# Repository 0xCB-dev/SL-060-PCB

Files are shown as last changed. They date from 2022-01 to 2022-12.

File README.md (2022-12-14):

# Synth Labs 060 PCB
## 60% Keyboard

Licence | OSHWA
:-------------------------:|:-------------------------:
 | (https://certification.oshwa.org/de000116.html)

### PCB:
KiCad version 6 Stable

#### Daughterboard
Top | Bottom
:-------------------------:|:-------------------------:
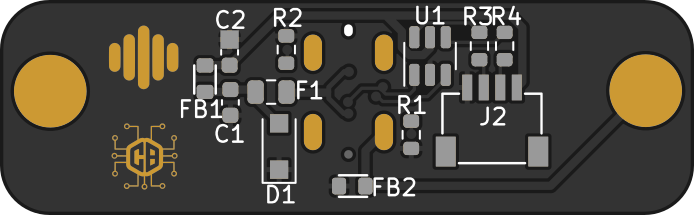
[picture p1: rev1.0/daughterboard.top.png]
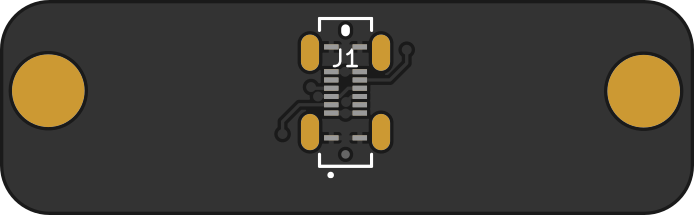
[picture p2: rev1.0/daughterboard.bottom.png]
  |  

#### Soldered PCB
Top | Bottom
:-------------------------:|:-------------------------:
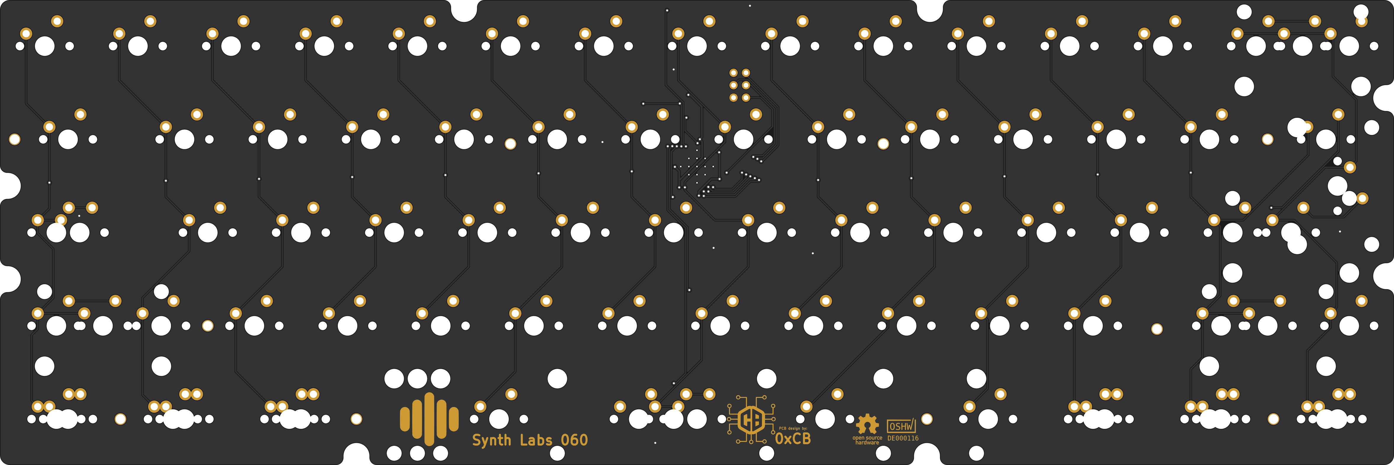
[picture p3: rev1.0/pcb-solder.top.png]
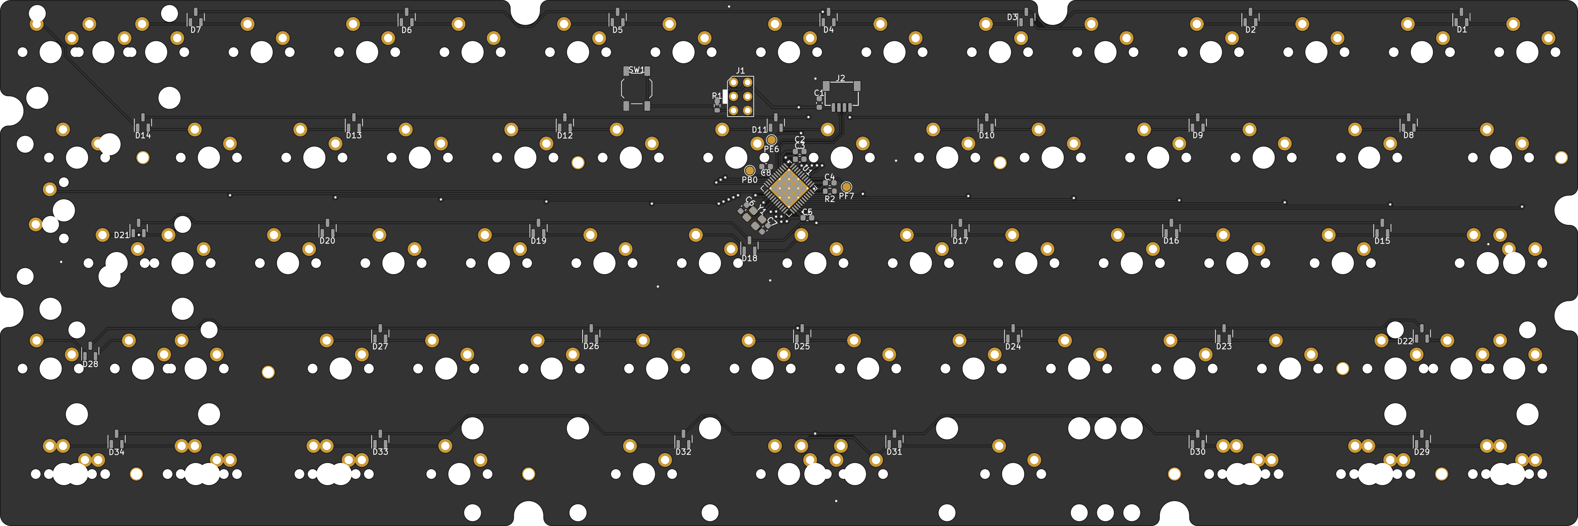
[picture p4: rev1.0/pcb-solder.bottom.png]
  |  

#### Hotswap PCB
Top | Bottom
:-------------------------:|:-------------------------:
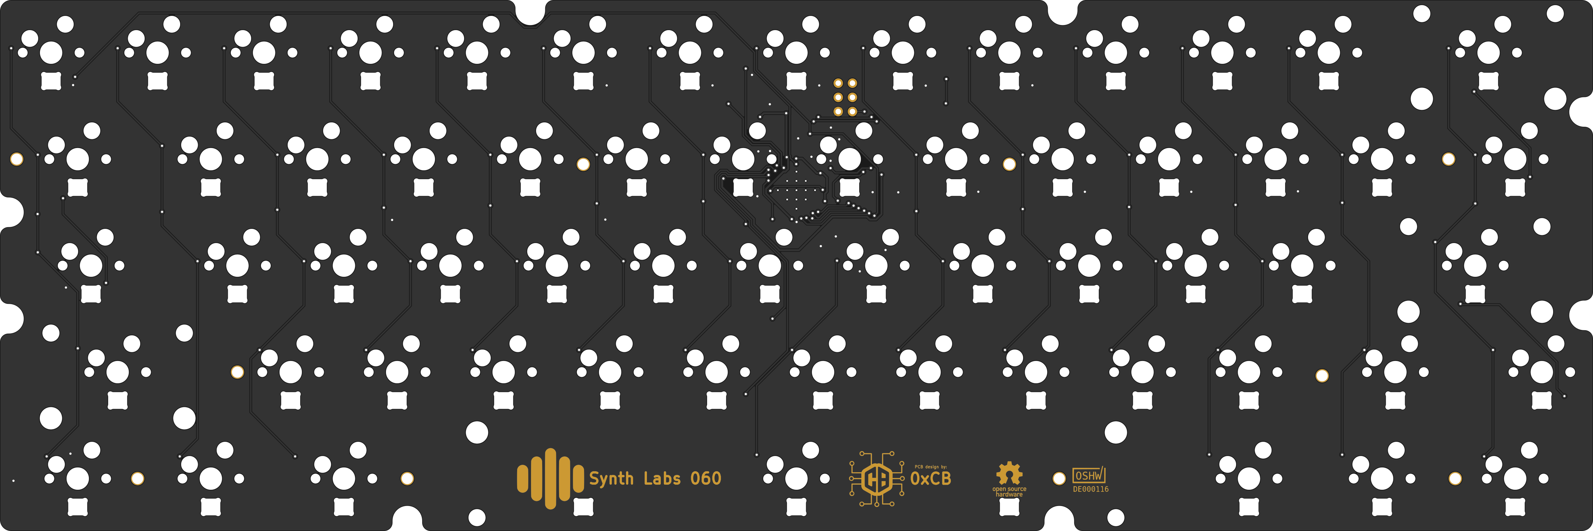
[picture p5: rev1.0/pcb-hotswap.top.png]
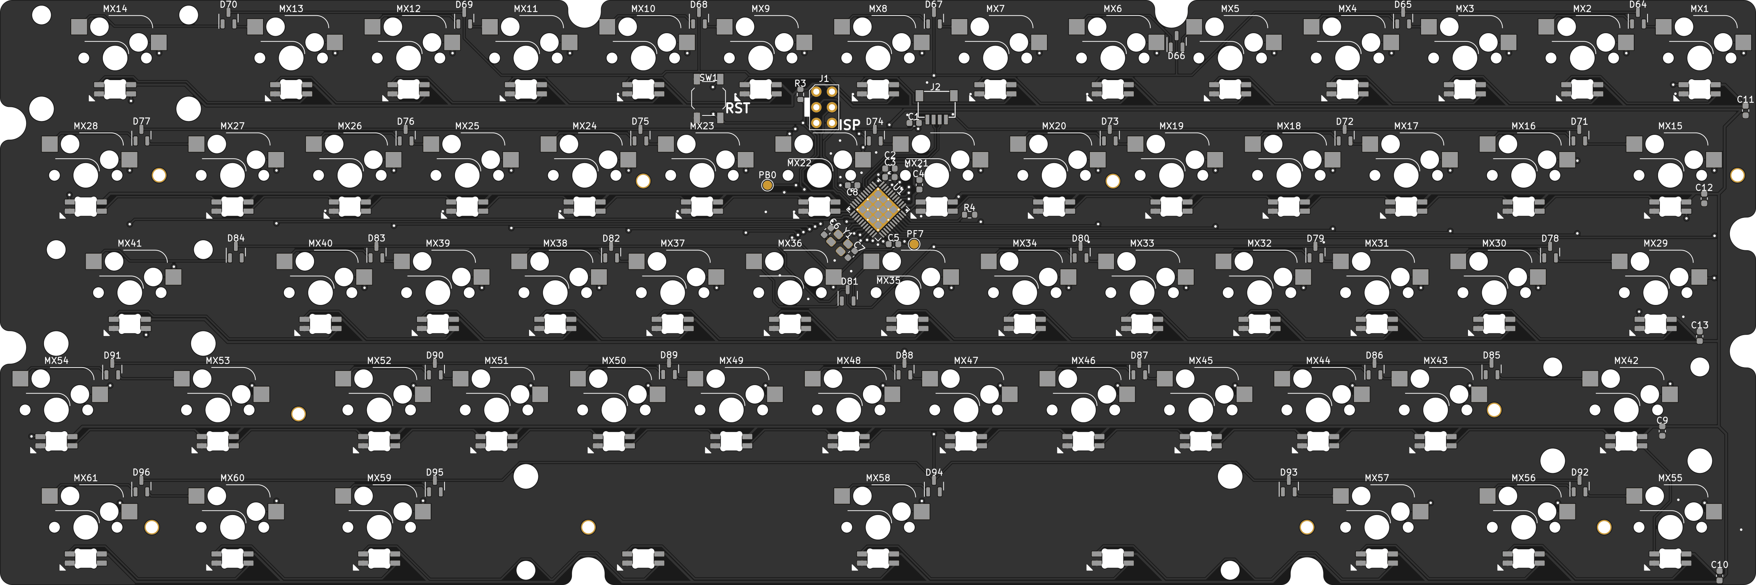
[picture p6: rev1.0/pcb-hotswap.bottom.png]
  |  

#### BOM:

[ibom daughterboard](https://files.0xcb.dev/0xCB/SL-060-PCB/daughterboard.html)

[ibom hotswap pcb](https://files.0xcb.dev/0xCB/SL-060-PCB/pcb-hotswap.html)

[ibom soldered pcb](https://files.0xcb.dev/0xCB/SL-060-PCB/pcb-solder.html)

##### Daughterboard

| References | Value | Footprint | Quantity | Mouser |
|---|---|---|---|---|
| J1 | USB4120-03-C | GCT_USB4070-30-C_REVC5 | 1 |  640-USB4070-30-C |
| J2 | Conn_01x04 | JST-SR-4 | 1 |  485-4208 |
| R1, R2 | 5.1k | R_0603_1608Metric | 2 |  667-ERA-3AED512V |
| R3, R4 | 22 | R_0603_1608Metric | 2 |  754-RG1608Q-220DT5 |
| U1 | USBLC6-2SC6  | SOT-23-6 | 1 |  511-USBLC6-2SC6 |
| C1 | 10u | C_0603_1608Metric | 1 |  80-C0603C106M8PLR |
| C2 | 1u | C_0603_1608Metric | 1 |  81-GCG188L8EE105KA7D  |
| F1 | 3A | Fuse_0805_2012Metric | 1 |  652-MF-PSML150/6-2 |
| D1 | SMF5.0CA | D_SOD-123F | 1 |  576-SMF5.0CA |
| FB1, FB2 | 600R | Ferrite_Bead_0603 | 2 |  81-BLM18KN601EH1D |

##### Soldered PCB

| References | Value | Footprint | Quantity | Mouser |
|---|---|---|---|---|
| J2 | Conn_01x04 | JST-SR-4 | 1 | 485-4208 |
| R1, R2 | 10k | R_0603_1608Metric | 2 | 754-RG1608N-103-BT5 |
| U1 | ATMEGA32U4 | QFN-44-1EP_7x7mm_P0.5mm_EP5.2x5.2mm_ThermalVias | 1 | 556-ATMEGA32U4-MU |
| Y1 | 16MHz | Crystal_SMD_3225-4Pin_3.2x2.5mm | 1 | 581-CX3225SB16H0PST |
| C2, C3, C4, C5 | 100n | C_0603_1608Metric | 4 | 80-C603C104K5RAC3121 |
| C1, C8 | 1u | C_0603_1608Metric | 2 | 81-GCG188L8EE105KA7D |
| C6, C7 | 22p | C_0603_1608Metric | 2 | 80-C0603C220J5G7411 |
| SW1 | SW_Push | SW_SPST_TL3342 | 1 | 611-PTS526SM15SMTR2L |
| D1, ..., D34 | BAV70 | SOT-23 | 34 | 241-BAV70_R1_00001 |

##### Hotswap PCB

| References | Value | Footprint | Quantity | Mouser |
|---|---|---|---|---|
| J2 | Conn_01x04 | JST-SR-4 | 1 | 485-4208 |
| R3, R4 | 10k | R_0603_1608Metric | 2 | 754-RG1608N-103-BT5 |
| U1 | ATMEGA32U4 | QFN-44-1EP_7x7mm_P0.5mm_EP5.2x5.2mm_ThermalVias | 1 | 556-ATMEGA32U4-MU |
| Y1 | 16MHz | Crystal_SMD_3225-4Pin_3.2x2.5mm | 1 | 581-CX3225SB16H0PST |
| C2, C3, C4, C5, C9, C10, C11, C12, C13 | 100n | C_0603_1608Metric | 9 | 80-C603C104K5RAC3121 |
| C1, C8 | 1u | C_0603_1608Metric | 2 | 81-GCG188L8EE105KA7D |
| C6, C7 | 22p | C_0603_1608Metric | 2 | 80-C0603C220J5G7411 |
| SW1 | SW_Push | SW_SPST_TL3342 | 1 | 611-PTS526SM15SMTR2L |
| D1, ..., D63 | SK6812MINI-E | MX_SK6812MINI-E | 63 | https://cdn-shop.adafruit.com/product-files/4960/4960_SK6812MINI-E_REV02_EN.pdf |
| D64, ..., D96 | BAV70 | SOT-23 | 33 | 241-BAV70_R1_00001 |
| MX* | MX | SW_Hotswap_Kailh_* | 61 | https://www.kailhswitch.com/mechanical-keyboard-switches/box-switches/kailh-rainbow-mx-hot-swapping-pcb-socket.html |

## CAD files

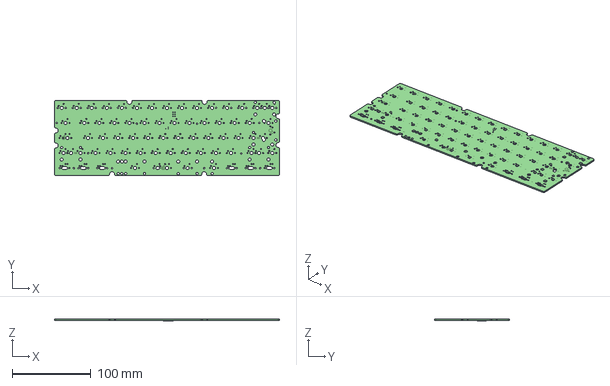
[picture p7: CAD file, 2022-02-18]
rev1.0/pcb-solder/pcb-solder.step
285.0 x 95.0 x 2.42 mm
pcb-solder PCB

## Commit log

2021-09-11 added hw
    [RGB.kicad_sch, daughterboard.kicad_pcb, daughterboard.kicad_sch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]
2021-09-19 updated edge.cuts
    [pcb-hotswap-B_Cu.gbr, pcb-hotswap-B_Mask.gbr, pcb-hotswap-B_Paste.gbr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]
2022-01-08 added 2D renders
    [daughterboard-B_Cu.gbr, daughterboard-B_Mask.gbr, daughterboard-B_Paste.gbr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]
2022-02-18 changed board outline
    [pcb-solder.step]
2022-02-20 changed hotswap PCB outline
2022-03-01 generated prod gerbers
    [daughterboard-B_Cu.gbr, daughterboard-B_Mask.gbr, daughterboard-B_Paste.gbr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]
2022-03-19 fixed JST mirror
    [daughterboard-B_Cu.gbr, daughterboard-B_Mask.gbr, daughterboard-B_Paste.gbr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]
2022-11-02 Fix Soldered BOM dead link in README
2022-11-05 fix error introduced in jst flip and move mounting holes
    [daughterboard-B_Cu.gbr, daughterboard-B_Mask.gbr, daughterboard-B_Paste.gbr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]
2022-12-12 Adjust standoff cutouts so margin around actual case is more even
2022-12-13 Change USB component on daughterboard to GCT USB4070-30-C
    [daughterboard.kicad_pcb]
2022-12-14 redone teardrops, gnd floods and gerbers
    [daughterboard-B_Cu.gbr, daughterboard-B_Mask.gbr, daughterboard-B_Paste.gbr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]
2022-12-16 Change "\" matrix position on hotswap PCB to match soldered PCB
    [matrix.kicad_sch]
2022-12-16 Move last diode in row 2 a bit further away from stabilizer hole, just for extra clearance
2022-12-17 redo teardrops and gerbers for the hotswap pcb
    [pcb-hotswap-B_Cu.gbr, pcb-hotswap-B_Mask.gbr, pcb-hotswap-B_Paste.gbr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]
2023-04-09 Flip JST on daughterboard side (again, to undo the previous one)
    [daughterboard.kicad_pcb, daughterboard.kicad_sch]
2023-04-09 Removed unnecessary via for U1 GND pin
    [daughterboard.kicad_pcb]
2023-04-24 Swap VCC and GND lines for all PCBs (universal pin out)
    [daughterboard.kicad_pcb, daughterboard.kicad_sch, pcb-hotswap.kicad_sch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]
2023-04-24 More cleanup on daughterboard
    [daughterboard.kicad_pcb]
2023-04-24 Remove unused teardrop zone on daughterboard
    [daughterboard.kicad_pcb]
2023-04-25 fix zones and gen gerbers
    [RGB.kicad_sch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]
